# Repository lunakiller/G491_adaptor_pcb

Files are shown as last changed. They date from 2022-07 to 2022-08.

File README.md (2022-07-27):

# STM32G491CCUx Adaptor PCB

Adaptor PCB for STM32G491CCUx. Contains 20MHz crystal oscillator, power and user LED and separate 3.3V voltage regulators both for digital and analog part. It is possible to use only one voltage regulator or a direct 3.3V supply, in which case it is mandatory to close the SB1 solderbridge.

All free pins are routed to the edge of the board.

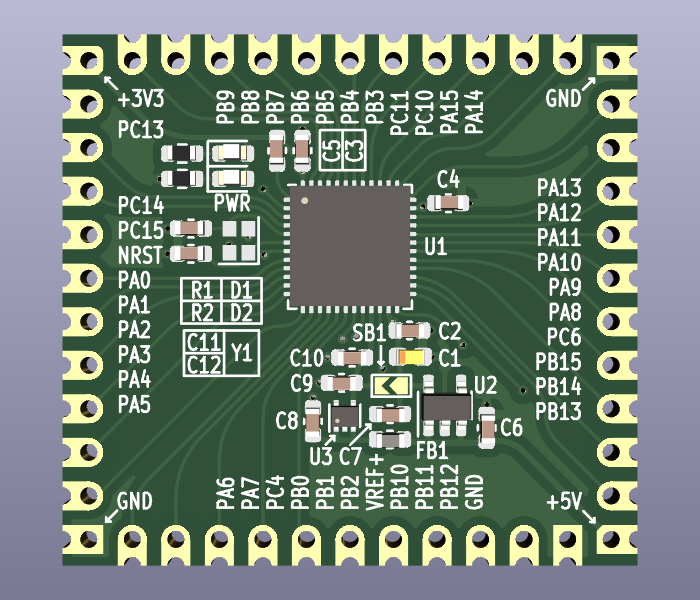
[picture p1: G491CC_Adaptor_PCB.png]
PCB render


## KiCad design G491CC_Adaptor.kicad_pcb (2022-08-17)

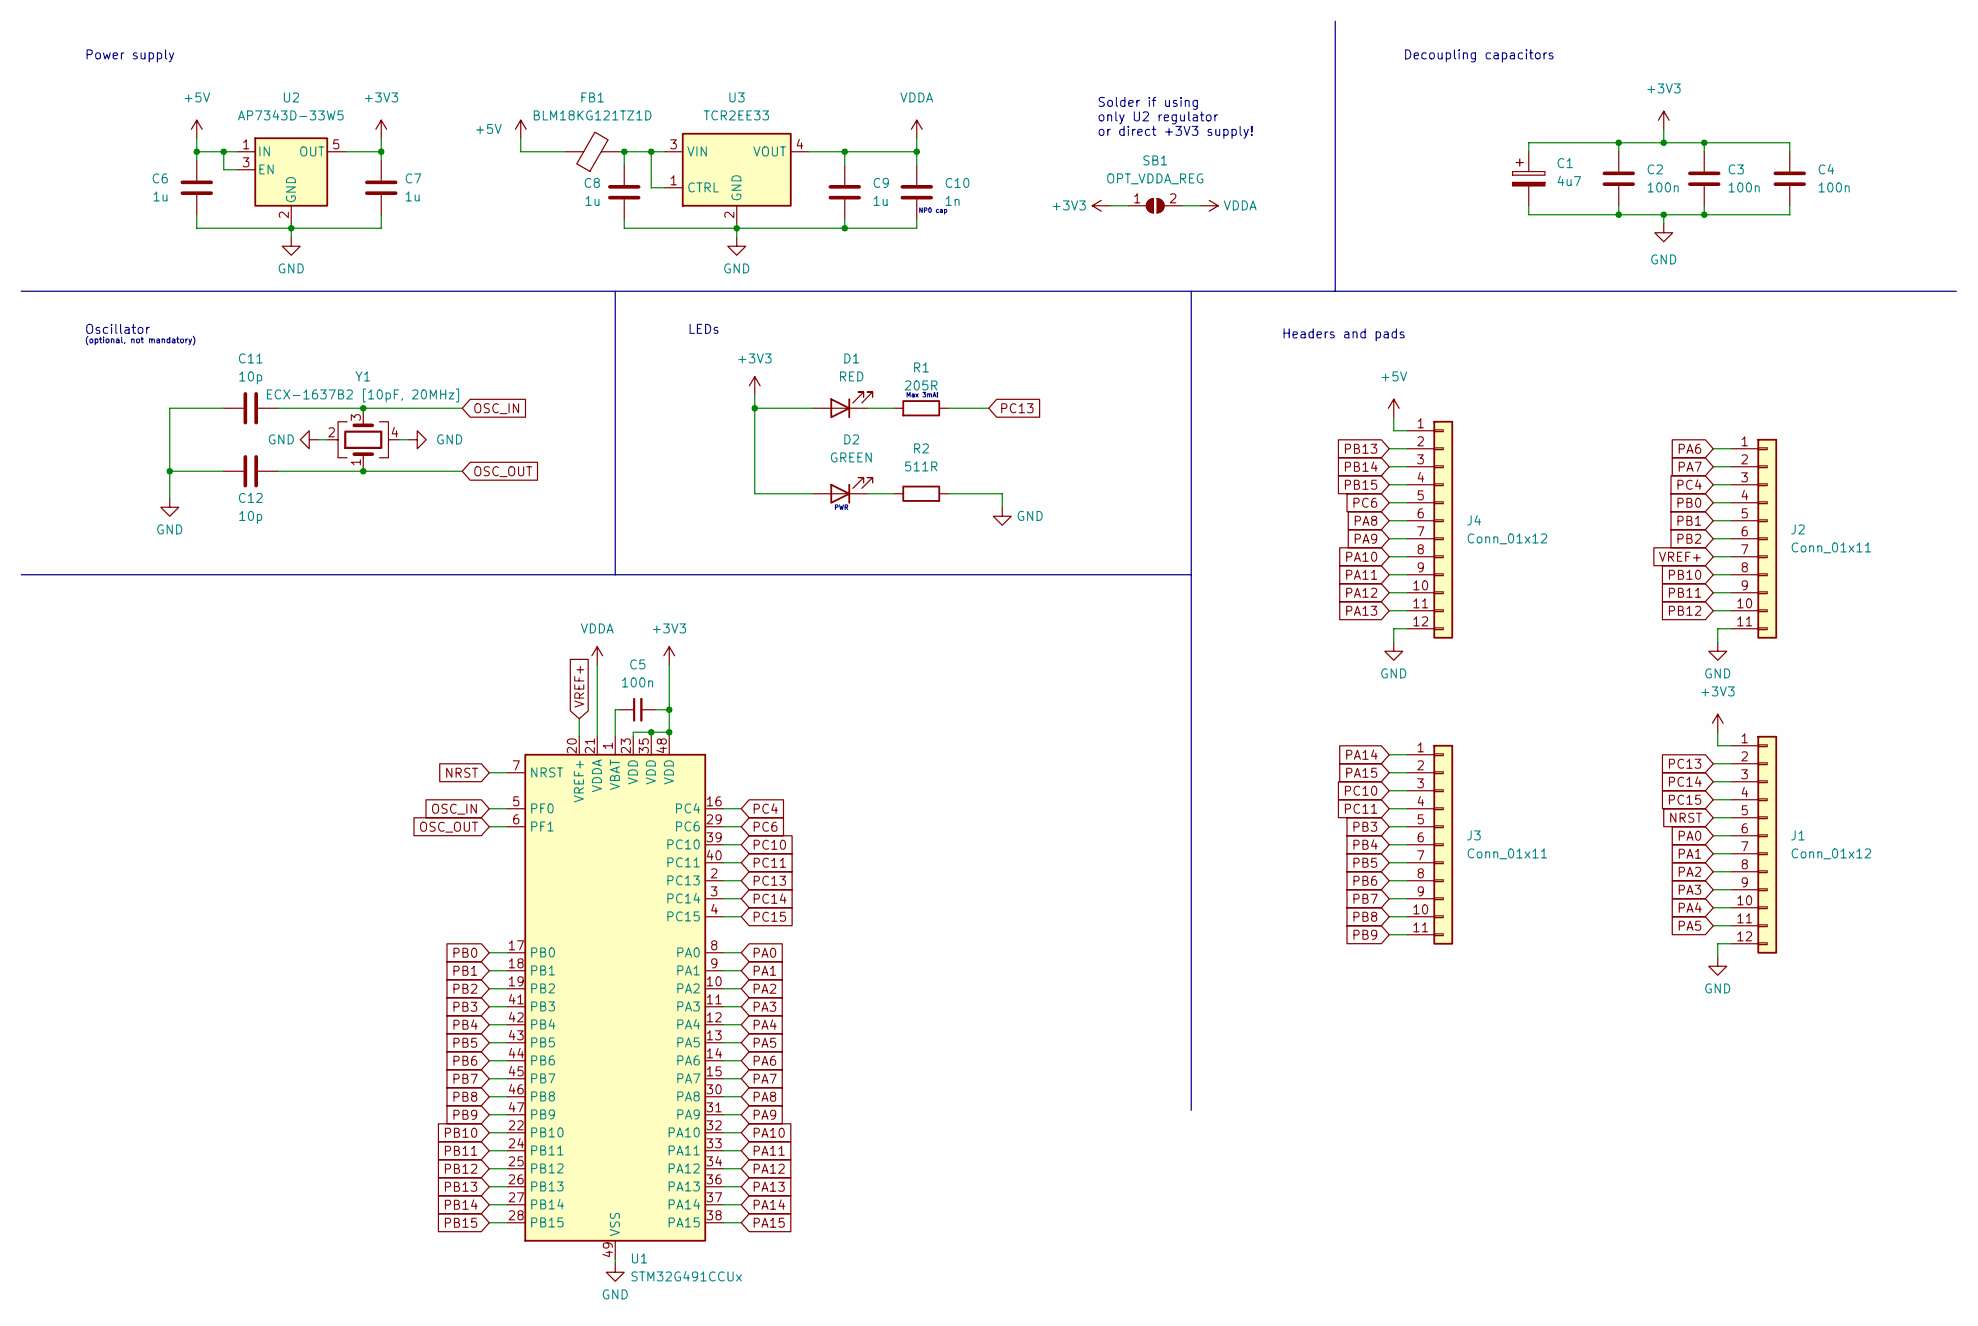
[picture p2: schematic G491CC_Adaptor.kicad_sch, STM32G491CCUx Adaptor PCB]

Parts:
C1: 4u7; CP_EIA-1608-10_AVX-L
C2, C3, C4, C5: 100n; C_0603_1608Metric
C6, C7, C8, C9: 1u; C_0603_1608Metric
C10: 1n; C_0603_1608Metric
C11, C12: 10p; C_0603_1608Metric
D1: RED; LED_0603_1608Metric
D2: GREEN; LED_0603_1608Metric
FB1: BLM18KG121TZ1D; L_0603_1608Metric
J1, J4: Conn_01x12; PinHeader_Castellated_1x12_P2.54mm_Vertical
J2, J3: Conn_01x11; PinHeader_Castellated_1x11_P2.54mm_Vertical
R1: 205R; R_0603_1608Metric
R2: 511R; R_0603_1608Metric
SB1: OPT_VDDA_REG; SolderJumper-2_P1.3mm_Smaller_Open_TrianglePad1.0x1.5mm
U1: STM32G491CCUx; QFN-48-1EP_7x7mm_P0.5mm_EP5.6x5.6mm
U2: AP7343D-33W5; SOT-23-5
U3: TCR2EE33; SOT-553
Y1: ECX-1637B2 [10pF, 20MHz]; Crystal_SMD_2016-4Pin_2.0x1.6mm

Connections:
+3V3: C1.1, C2.1, C3.1, C4.1, C5.2, C7.1, D1.2 (A), D2.2 (A), J1.1, SB1.1 (A), U1.23 (VDD), U1.35 (VDD), U1.48 (VDD), U2.5 (OUT)
+5V: C6.1, FB1.1, J4.1, U2.1 (IN), U2.3 (EN)
GND: C1.2, C2.2, C3.2, C4.2, C6.2, C7.2, C8.2, C9.2, C10.2, C11.1, C12.1, J1.12, J2.11, J4.12, R2.2, U1.49 (VSS), U2.2 (GND), U3.2 (GND), Y1.2, Y1.4
NRST: J1.5, U1.7 (NRST)
unnamed: C5.1, U1.1 (VBAT)
unnamed: C8.1, FB1.2, U3.1 (CTRL), U3.3 (VIN)
unnamed: D1.1 (K), R1.2
unnamed: D2.1 (K), R2.1
OSC_IN: C11.2, U1.5 (PF0), Y1.3
OSC_OUT: C12.2, U1.6 (PF1), Y1.1
PA0: J1.6, U1.8 (PA0)
PA1: J1.7, U1.9 (PA1)
PA2: J1.8, U1.10 (PA2)
PA3: J1.9, U1.11 (PA3)
PA4: J1.10, U1.12 (PA4)
PA5: J1.11, U1.13 (PA5)
PA6: J2.1, U1.14 (PA6)
PA7: J2.2, U1.15 (PA7)
PA8: J4.6, U1.30 (PA8)
PA9: J4.7, U1.31 (PA9)
PA10: J4.8, U1.32 (PA10)
PA11: J4.9, U1.33 (PA11)
PA12: J4.10, U1.34 (PA12)
PA13: J4.11, U1.36 (PA13)
PA14: J3.1, U1.37 (PA14)
PA15: J3.2, U1.38 (PA15)
PB0: J2.4, U1.17 (PB0)
PB1: J2.5, U1.18 (PB1)
PB2: J2.6, U1.19 (PB2)
PB3: J3.5, U1.41 (PB3)
PB4: J3.6, U1.42 (PB4)
PB5: J3.7, U1.43 (PB5)
PB6: J3.8, U1.44 (PB6)
PB7: J3.9, U1.45 (PB7)
PB8: J3.10, U1.46 (PB8)
PB9: J3.11, U1.47 (PB9)
PB10: J2.8, U1.22 (PB10)
PB11: J2.9, U1.24 (PB11)
PB12: J2.10, U1.25 (PB12)
PB13: J4.2, U1.26 (PB13)
PB14: J4.3, U1.27 (PB14)
PB15: J4.4, U1.28 (PB15)
PC4: J2.3, U1.16 (PC4)
PC6: J4.5, U1.29 (PC6)
PC10: J3.3, U1.39 (PC10)
PC11: J3.4, U1.40 (PC11)
PC13: J1.2, R1.1, U1.2 (PC13)
PC14: J1.3, U1.3 (PC14)
PC15: J1.4, U1.4 (PC15)
VDDA: C9.1, C10.1, SB1.2 (B), U1.21 (VDDA), U3.4 (VOUT)
VREF+: J2.7, U1.20 (VREF+)

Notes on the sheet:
PWR
NP0 cap
Oscillator
Max 3mA!
LEDs
Headers and pads
Decoupling capacitors
Solder if using only U2 regulator or direct +3V3 supply!
(optional, not mandatory)
Power supply

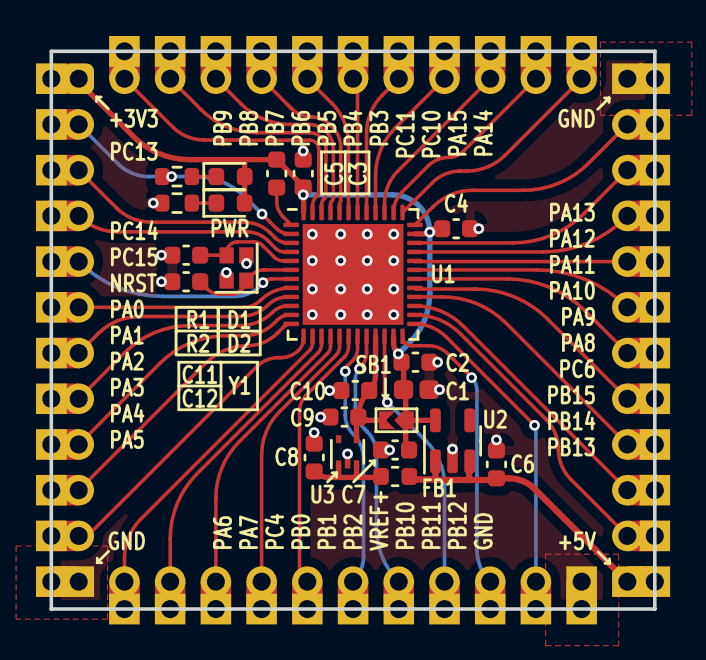
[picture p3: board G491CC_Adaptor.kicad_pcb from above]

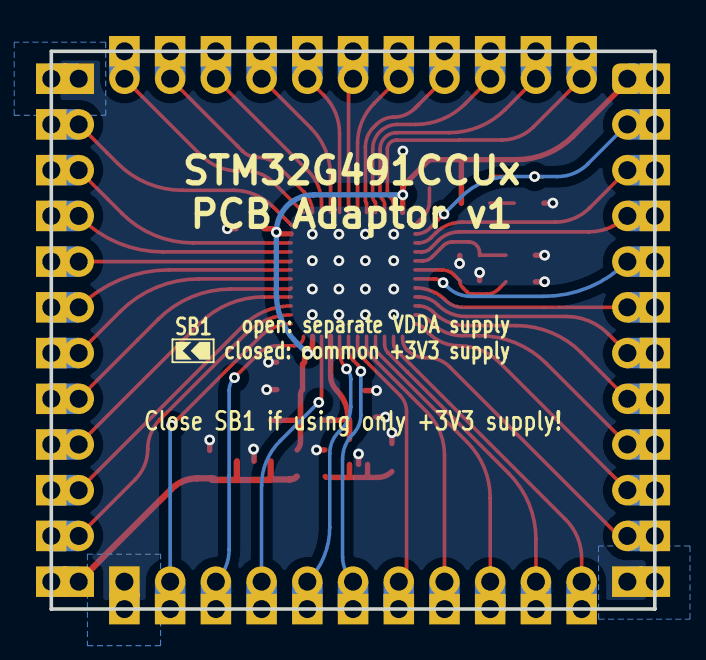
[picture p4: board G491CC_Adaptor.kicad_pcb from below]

Board: 2 copper layers, 33.5 x 31.0 mm, 26 parts (4 on the bottom side), 51 nets.
